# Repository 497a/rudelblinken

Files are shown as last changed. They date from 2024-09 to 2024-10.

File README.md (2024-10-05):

# rudelblinken

Synced blinking catears

## Notes

Less of a Readme, more a unstructured braindump

## Updating all cat ears nearby

_If builders built buildings the way programmers wrote programs, then the first woodpecker that came along would destroy civilization._ - Gerald Weinberg

Sometimes you may want to update all cat ears. This is the (for now untested) protocol I would use:

1. Make sure you have jaguar version `v1.41.0` installed. Running `nix develop` in this repo will install it for you.

2. Setup an WiFi AP on channel 6 with the SSID: `rudelctrl` and the password `22po7gl334ai`. On linux you can use the following command:

```
sudo create_ap --freq-band 2.4 -c 6 YOUR_WIFI_DEVICE YOUR_WIFI_DEVICE 'rudelctrl' '22po7gl334ai'
```

I usually use a second laptop for that.

3. Connect your machine to the AP

4. Make sure UDP port 1990 is open on your machine

5. Turn on your own cat ears and run `jag scan` to verify you can find them and figure out their name. Then try `jag container install rudelblinken main.toit -d NAME_OF_YOUR_CATEARS` to verify that everything works on your device.

6. Run around with your devices like a mad cat and run `make install-all` repeatedly to update all cat ears in range

## Hardware

rudelblinken is based on ESP32-C3 supermicro boards. Each device controls a single color LED strip. This should keep the hardware setup quite, simple requiring only a esp board, a mosfet, an LED strip and some wires for each node.

For now I just blink the builtin LEDs of the boards, more detail will follow once I built the actual hardware.

## Software stack

The software for rudelblinken is written in [toit](https://toitlang.org/), a high-level language designed for ESP32 programming. The devices are flashed with the [jaguar](https://github.com/toitlang/jaguar) firmware, which makes it possible to deploy toit programs over WiFi. Each device tries to connect to a hotspot named `rudelctrl` with the password `22po7gl334ai`. It is important that you use channel 6. You can start an AP with that configuration using `make start-ap`. You can also set your own WiFi and password when flashing the devices.

The devices communicate using the [ESP-NOW](https://docs.espressif.com/projects/esp-idf/en/stable/esp32/api-reference/network/esp_now.html) protocol. ESP-NOW was choosen over WiFi, because WiFi is not connectionless. ESP-NOW was choosen over BLE, because it seems like the only way for connectionless communication. There are BLE advertisments but the ESP does not have an API to send a single advertisment, only to start sending in a given interval. ESP-NOW uses WiFi vendor-specific action frames. As it is using the WiFi hardware, it is limited to operating on the same channel as our WiFi connection. To receive messages from other devices they need to use the same channel. For rudelblinken this is channel 6. There are some limitations, when using ESP-NOW and WiFi at the same time.

For this reason toit does not allow ESP-NOW and WiFi to coexist. To fix this issue we use a [custom envelope](https://github.com/zebreus/toit-envelope-with-espnow) with a patched version of toit, that has removed the checks for coexistance and is patched so the ESP-NOW channel follows the WiFi channel and defaults to 6. So when you are flashing your esps with jaguar you need to use the custom envelope. The custom envelope also has a patch that lets any program access the name of the device. To built the patched firmware and flash a device with it run `make flash-DEVICENAME`.

Flashed devices will attempt to connect with the control AP and can be programmed via WiFi. Use `make run-all` to run the main program on all connected devices. Use `make install-all` to install the main program over multiple reboots on all devices. `make uninstall-all` to uninstall on all devices.

## Build instructions

You can find some basic instructions on how to build your own rudelblinken cat ears based on a ESP32-C3 supermini board at https://md.darmstadt.ccc.de/rudelblinken-mrmcd

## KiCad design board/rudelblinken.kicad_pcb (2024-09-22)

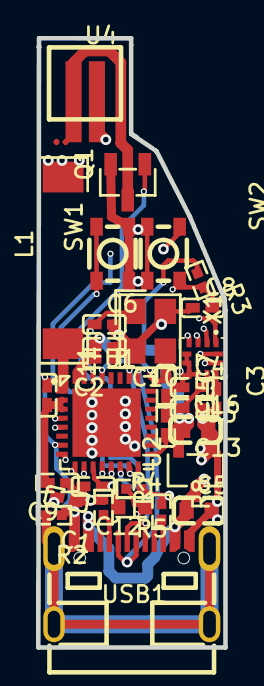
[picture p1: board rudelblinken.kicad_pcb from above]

Board: 4 copper layers, 10.4 x 33.8 mm, 31 parts (0 on the bottom side), 22 nets.

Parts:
C1, C2, C13: 10uF; C0402
C3, C4, C9, C12, C15: 100nF; C0402
C5, C16: 22uF; C0603
C6, C7: 22pF; C0402
C8, C10, C11: 1uF; C0402
L1: AN9520-245; ANT-SMD_L9.5-W2.1
Q1: AO3400A; SOT-23-3_L2.9-W1.3-P1.90-LS2.4-BR
R2: 1MΩ; R0402
R3, R5: 10kΩ; R0402
R4: ALS-PT19-315C/L177/TR8; SENSORS-SMD_ALS-PT19
R7, R8: 5.1kΩ; R0402
SW1, SW2: K2-1830UQ-A4DW-06; KEY-SMD_4P-L3.0-W2.6-P1.80-LS3.5
U1: ESP32-C3FH4; QFN-32_L5.0-W5.0-P0.50-TL-EP3.7
U2: XC6206P332MR; SOT-23-3_L2.9-W1.6-P1.90-LS2.8-BR
U4: LED strip; LED STRIP 4MM
U5: LIS2DH12TR; LGA-12_L2.0-W2.0-P0.50-BL
USB1: MC-107D; USB-C-SMD_MC-107D
X1: 40MHz; CRYSTAL-SMD_4P-L3.2-W2.5-BL

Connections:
3.3V: C1.2, C2.2, C3.1, C4.2, C9.2, C10.2, C11.2, C12.1, C13.2, C15.2, C16.1, R3.1, R4.1, U1.2, U1.3, U1.11, U1.17, U1.31, U1.32, U2.2, U5.9, U5.10
ACC_CLK: U1.5, U5.1
ACC_CS: U1.4, U5.2
ACC_INT1: U1.12, U5.12
ACC_INT2: U1.13, U5.11
ACC_SDI: U1.9, U5.4
ACC_SDO: U1.10, U5.3
AMBIENT: R4.2, R5.2, U1.8
ANTENNA: L1.1, U1.1
BOOT: SW1.1, SW1.2, U1.15
CC1: R7.2, USB1.A5
CC2: R8.2, USB1.B5
D+: U1.26, USB1.A6, USB1.B6
D-: U1.25, USB1.A7, USB1.B7
GND: C1.1, C2.1, C3.2, C4.1, C5.2, C6.2, C7.2, C8.1, C9.1, C10.1, C11.1, C12.2, C13.1, C15.1, C16.2, L1.2, Q1.2, R2.1, R5.1, R7.1, R8.1, SW1.3, SW1.4, SW2.3, SW2.4, U1.33, U2.1, U5.5, U5.6, U5.7, U5.8, USB1.A1B12, USB1.B1A12, X1.2, X1.4
LED: Q1.1, U1.14
RESET: C8.2, R3.2, SW2.1, SW2.2, U1.7
SHIELD: R2.2, USB1.0
U4_1: Q1.3, U4.1
VBUS: C5.1, U2.3, U4.2, USB1.A4B9, USB1.B4A9
XTAL_N: C7.1, U1.29, X1.3
XTAL_P: C6.1, U1.30, X1.1

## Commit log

2024-09-11 First prototype for synchronized blinking
2024-09-17 Add target for flashing devices
2024-09-22 Import board from easyeda
    [Sheet_1.kicad_sch, Sheet_2.kicad_sch, rudelblinken.kicad_pcb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]
2024-09-22 Add kicad and easyeda2kicad
2024-09-22 Organize schematics for kicad
    [Sheet_1.kicad_sch, Sheet_2.kicad_sch, rudelblinken.kicad_sch]
2024-09-22 Fix kicad
2024-09-22 Add kicad autosave files to gitignore
2024-09-22 Download kicad parts from lcsc
2024-09-30 Add support for the ambient light sensor
2024-10-03 Adjust led brightness curve
2024-10-03 Fix led calibration
2024-10-03 Add ambient light sensor support
2024-10-03 Pin jaguar version
2024-10-05 Remove kicad from the nix shell
